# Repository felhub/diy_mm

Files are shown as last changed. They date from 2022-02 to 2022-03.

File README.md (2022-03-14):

# diy_mm

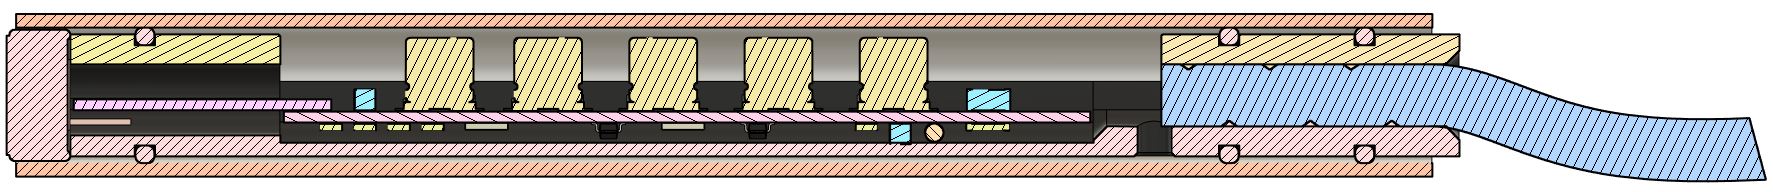
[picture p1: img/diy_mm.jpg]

Low cost (less than 10€) measurement microphone powered by +48V phantom power using a cheap electret capsule.
### Technical Data

| spec | value | unit | measured  |
|:---:|:---:|:---:|:---:|
| Frequency Response | 20 to 20000 &pm; 3dB  | Hz | n |
| Polar Pattern | Omnidirectional | - | n |
| Sensititvity | 0.013 | V/Pa @ 1kHz | y |
| Power requirements | +12 to +48 | V | y |
| Max acoustic input | 140dB | SPL | y |
| Output | XLR-3 (balanced) | - | - |
| Output Impedance | 100 | Ohm | y |
| Signal to Noise | 60dBA | SPL | n |
| Temp Operating Range  | -20 to 70 | °C | n |
| Dimensions L x D | 107.2 x 12 | mm | y |
| Weight | 16 (120 with 3m cable)| g | y |

### Measured Frequency Response

frequency response

## Impedance Converter and capsule adapter (kicad)

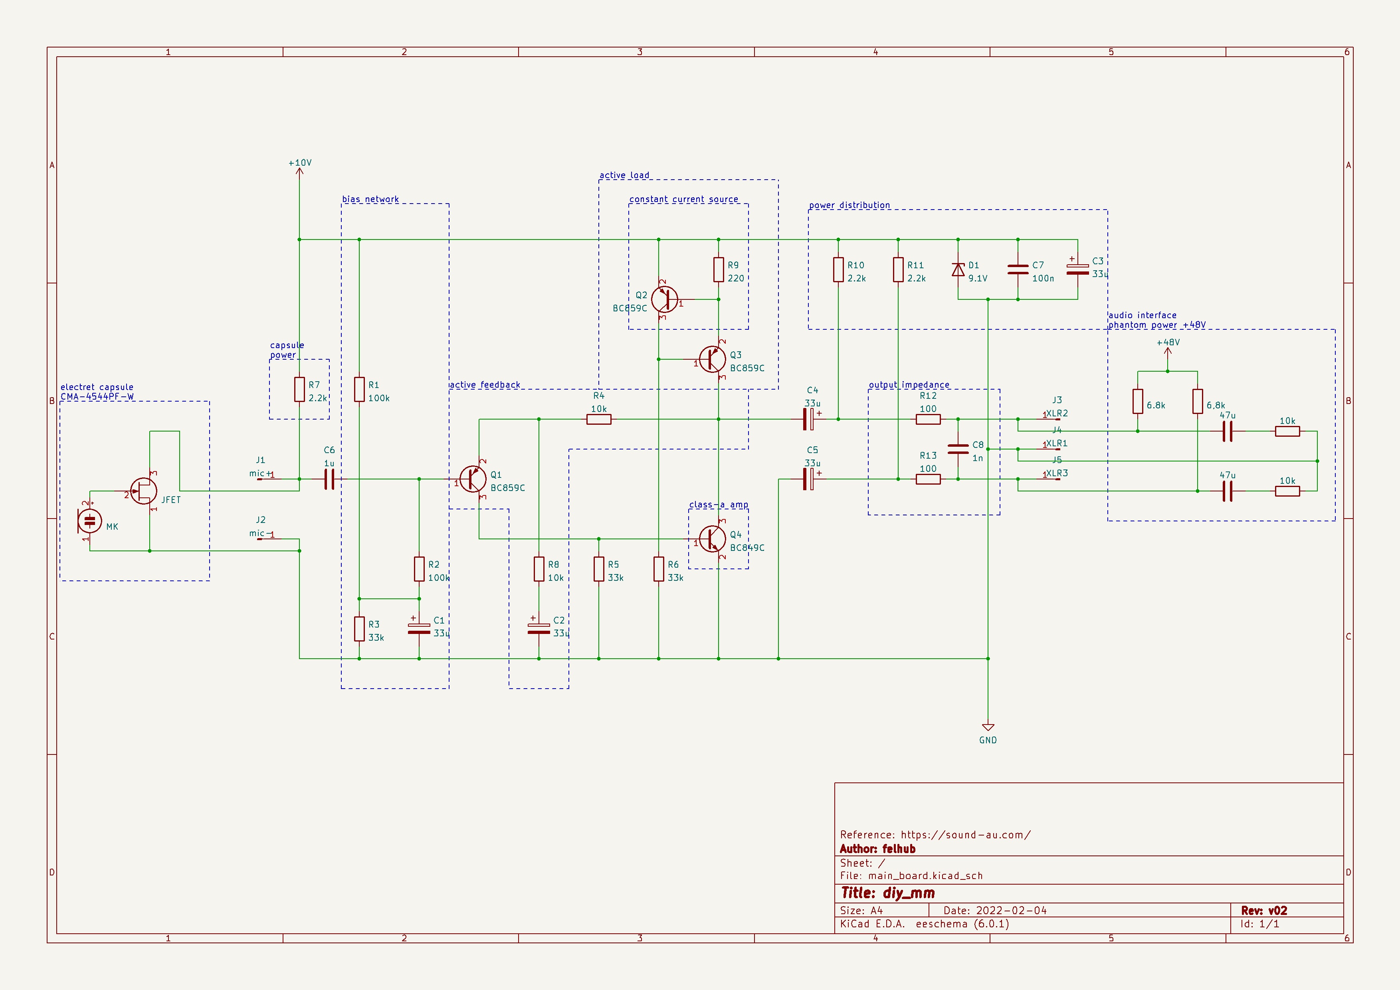
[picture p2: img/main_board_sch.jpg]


The impedance converter is based on an electret mic preamp from [Rod Elliot](https://sound-au.com), big thanks to the work he does on his site. He also has a store, where you can buy his original PCB for this amp, and many others. You can also donate there.  

Some changes were made to fit the converter to the capsule and to use smaller capacitors to fit it into the housing. Unfortunately these changes also effect the performance slightly.

In order to connect the PCB to the capsule and also to fix the capsule in place a small adapter PCB is used. This PCB is clamped in the 3d printed housing an soldered onto the converters PCB.

| main_board | capsule_adapter |
|:---:|:---:|
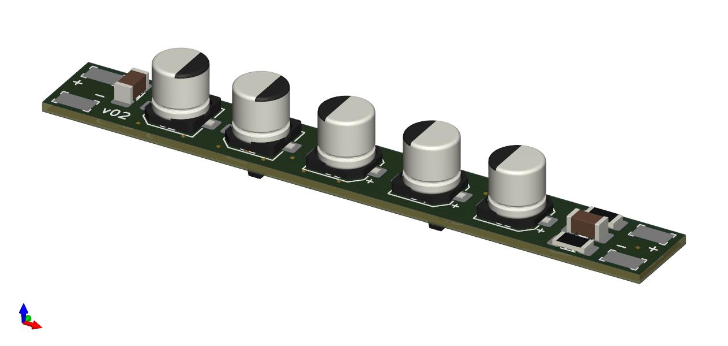
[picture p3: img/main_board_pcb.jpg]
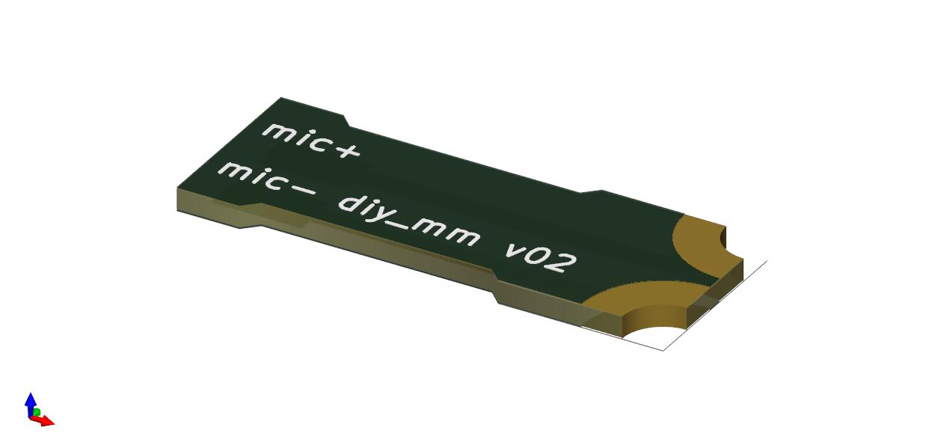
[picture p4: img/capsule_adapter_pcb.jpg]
|  |  |

## LTSpice Simulation (simulation)

Alongside the changes of the converter design a LTSpice simulation was conducted. The obtained result is very good, showing linearity of &pm;0.1dB and a very true phase slowly rising below 100Hz to reach \~13&deg; at 20Hz. The impedance converter also features a signal amplification of \~3dB.

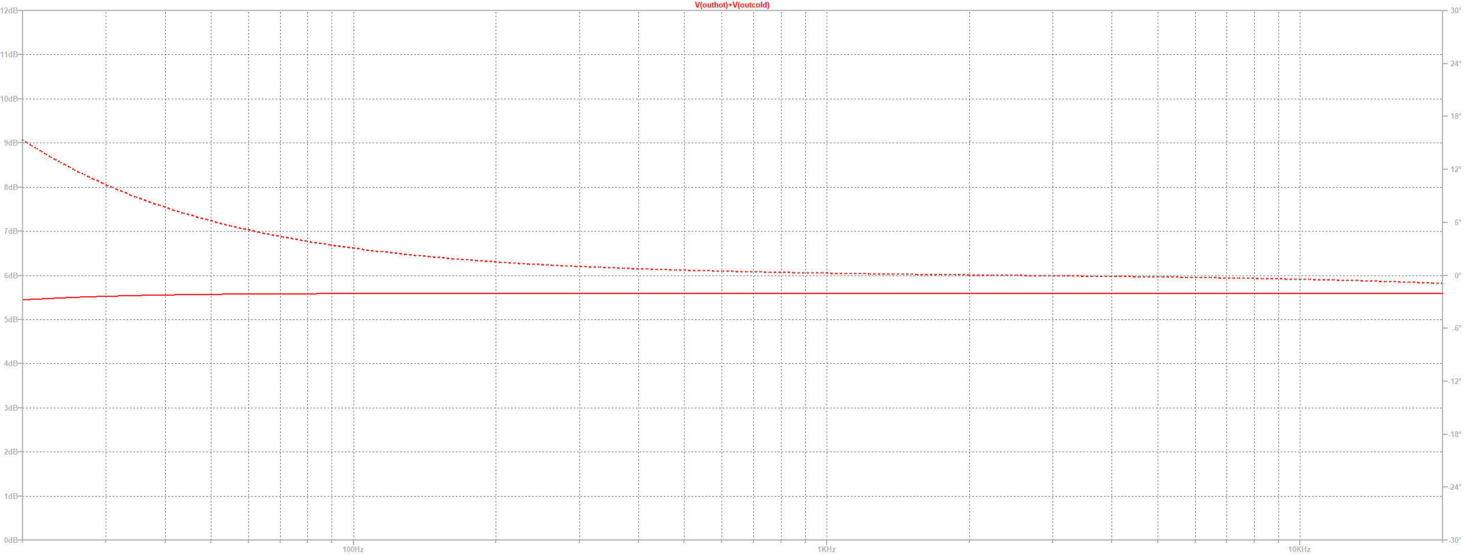
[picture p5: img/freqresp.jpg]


## 3D printed parts (3dfiles)

The fixture for capsule, impedance converter and strain relief if the cable are accomplished by three 3d printed parts. Using a 0.25mm nozzle the parts can be printed very accurately to perfectly fit the shielding aluminium tube using three o-rings.

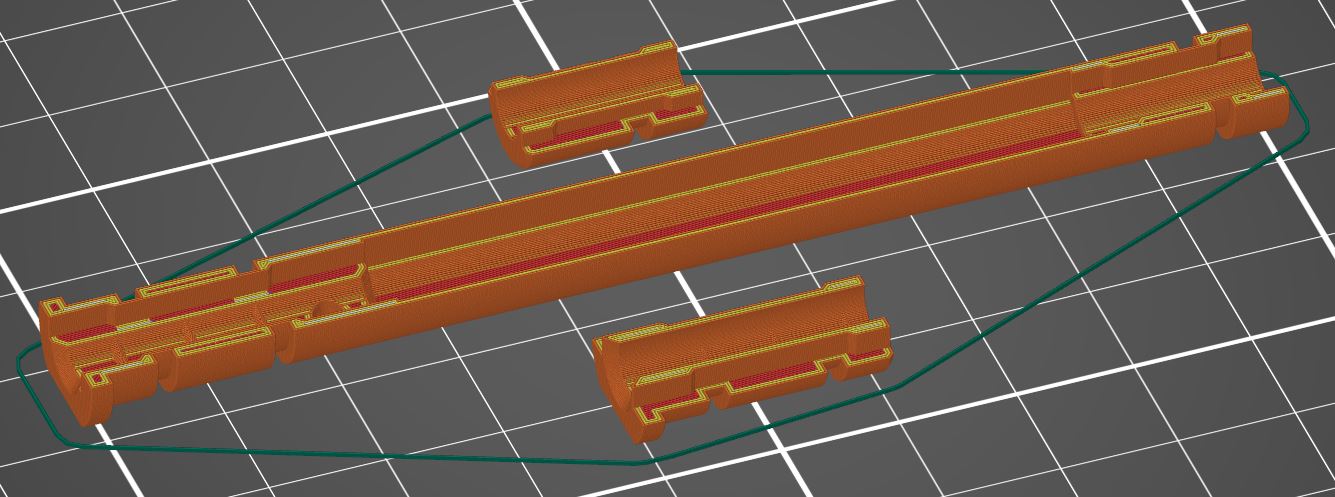
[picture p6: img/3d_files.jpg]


Through a hole in the chassis at the strain relief side, the shielding can be fed through in order to touch the aluminium tube. The hole assembly slides tightly inside and is just hold by friction. To get it back out one has to firstly pull on the cable slightly, after the first o-ring is out one should pull on the plastic to fully slide out the main assembly.

## Array configuration
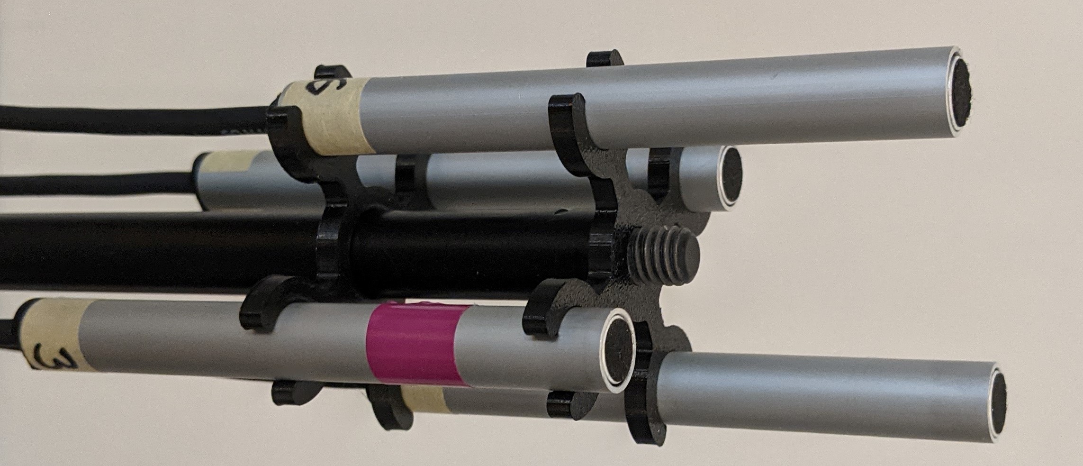
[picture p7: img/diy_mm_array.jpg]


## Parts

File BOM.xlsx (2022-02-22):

diy_mm
Bill of Materials
 |  |  |  |  |  |  |  |  | €9.369
Reference | Value | Footprint | Name | Comment | Supplier | Art. Nr. | Price/Pcs | Pcs | Total | Status
electric components
MK |  |  | CMA-4544PF-W | capsule | mouser.at | 490-CMA-4544PF-W | €0.620 | 1 | €0.62 | 30
Q1-Q3 |  | SOT-23-3 BEC | BC859C | pnp | conrad.at | 153145 | €0.080 | 3 | €0.24 | 90
Q4 |  | SOT-23-3 BEC | BC849C | npn | conrad.at | 152907 | €0.090 | 1 | €0.09 | 30
C1-C5 | 33u | 5x5.5 | WCAP-ASLI 865080442006 | 25v | mouser.at | 710-865080442006 | €0.164 | 5 | €0.82 | 150
C6 | 1u | 1206 | MLCC 885012208093 | ceramic | mouser.at | 710-885012208093 | €0.162 | 1 | €0.16 | 30
C7 | 100n | 1206 | MLCC 885012208087 | ceramic | mouser.at | 710-885012208087 | €0.090 | 1 | €0.09 | 30
C8 | 1n | 1206 | MLCC 885012208075 | ceramic | mouser.at | 710-885012208075 | €0.075 | 1 | €0.07 | 30
D1 | 10V | SOD-80C | Vishay 78-BZT55C9V1 | zener | mouser.at | 78-BZT55C9V1 | €0.165 | 1 | €0.17 | 30
R1-R2 | 100k | 1206 |  | 1% 0.25W | mouser.at | 652-CR1206FX-1003ELF | €0.013 | 2 | €0.03 | 60
R3, R5-R6 | 33k | 1206 |  | 1% 0.25W | mouser.at | 652-CR1206FX-3302ELF | €0.026 | 4 | €0.10 | 120
R4, R8 | 10k | 1206 |  | 1% 0.25W | mouser.at | 652-CR1206FX-1002ELF | €0.013 | 1 | €0.01 | 30
R9 | 220 | 1206 |  | 1% 0.25W | mouser.at | 652-CR1206FX-2200ELF | €0.032 | 1 | €0.03 | 30
R7, R10-R11 | 2.2k | 1206 |  | 1% 0.25W | mouser.at | 652-CR1206FX-2201ELF | €0.018 | 3 | €0.05 | 90
R12-R13 | 100 | 1206 |  | 1% 0.25W | mouser.at | 652-CR1206FX-1000ELF | €0.015 | 2 | €0.03 | 60
 |  |  | Sommer Cable The Goblin BK | per meter | thomann.de | 160823 | €1.090 | 3 | €3.27 | 90
 |  |  | Neutrik NC3 MXX | male XLR | thomann.de | 182696 | €2.880 | 1 | €2.88 | 30
mechanical components
 |  |  | Rundrohr Alu eloxiert 12x1 | per meter | hornbach.at | 6449190 | €3.040 | 0.104 | €0.32 | 3.12
 |  |  |  | incl. Shipping | jlcpcb.com |  | €0.174 | 1 | €0.17 | 30
 |  |  | NBR-70 O-Ring 6.00x1.50Ø | 3x | persicaner.at | 1571483 | €0.029 | 3 | €0.09 | 90
 |  |  | cable_clamp | 3d print |  |  | €0.030 | 1 | €0.03 | 30
 |  |  | capsule_clamp | 3d print |  |  | €0.020 | 1 | €0.02 | 30
 |  |  | chassis_oring | 3d print |  |  | €0.070 | 1 | €0.07 | 30

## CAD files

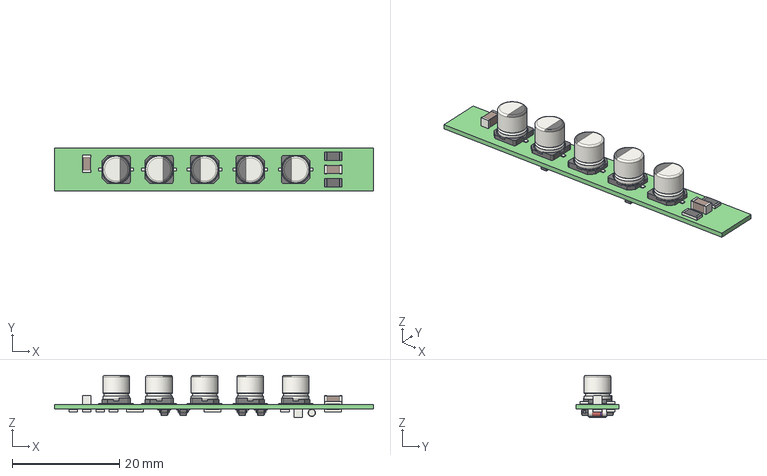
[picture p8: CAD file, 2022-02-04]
kicad/main_board/main_board.step
59.5 x 8.00 x 7.90 mm
main_board PCB

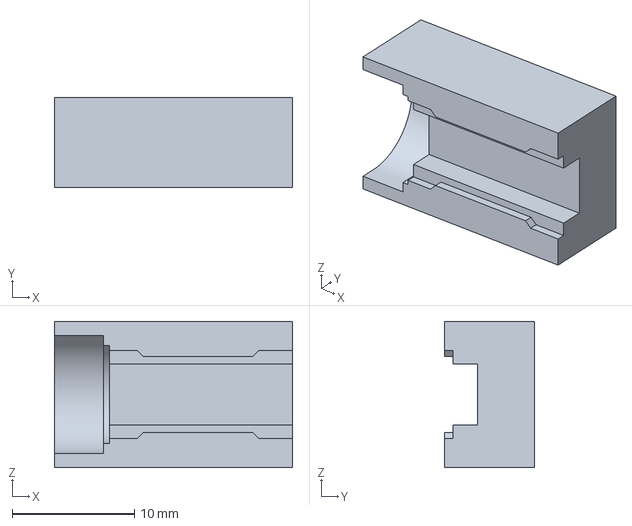
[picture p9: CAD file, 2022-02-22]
3d files/solder_jig.3mf
19.5 x 7.40 x 12.0 mm

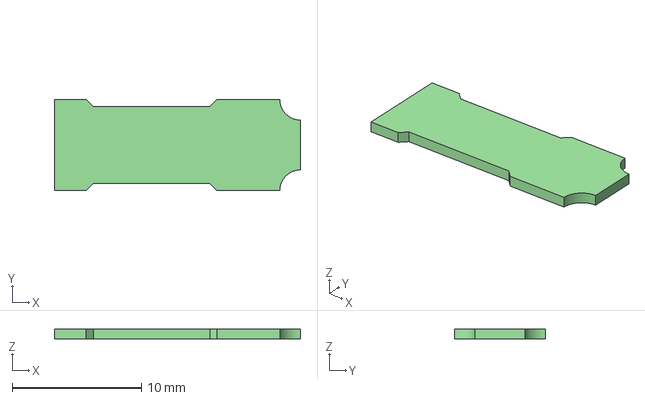
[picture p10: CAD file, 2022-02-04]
kicad/capsule_adapter/capsule_adapter.step
19.0 x 7.05 x 0.8 mm

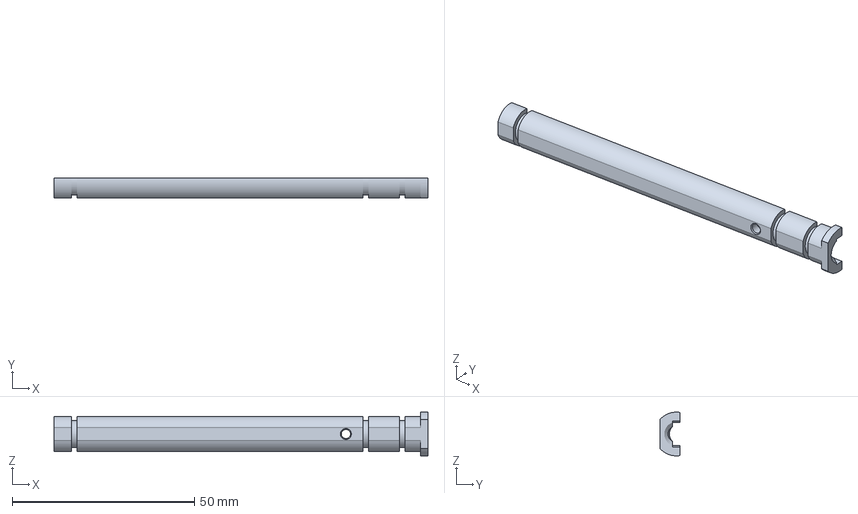
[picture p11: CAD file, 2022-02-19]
3d files/chassis.3mf
102.5 x 5.50 x 12.0 mm

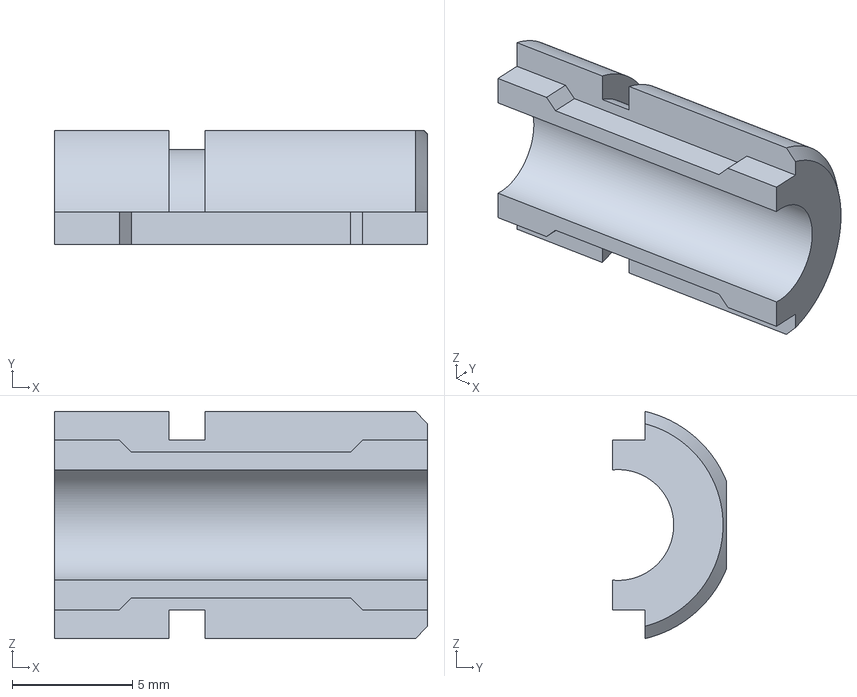
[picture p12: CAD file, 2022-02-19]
3d files/capsule_clamp.3mf
15.5 x 4.75 x 9.45 mm

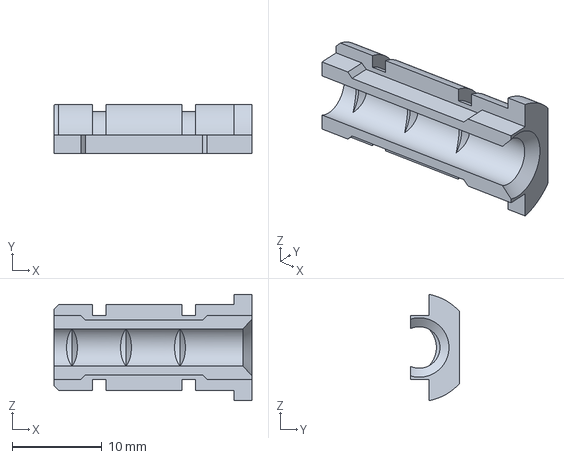
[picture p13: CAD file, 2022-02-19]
3d files/cable_clamp.3mf
22.0 x 5.50 x 11.8 mm

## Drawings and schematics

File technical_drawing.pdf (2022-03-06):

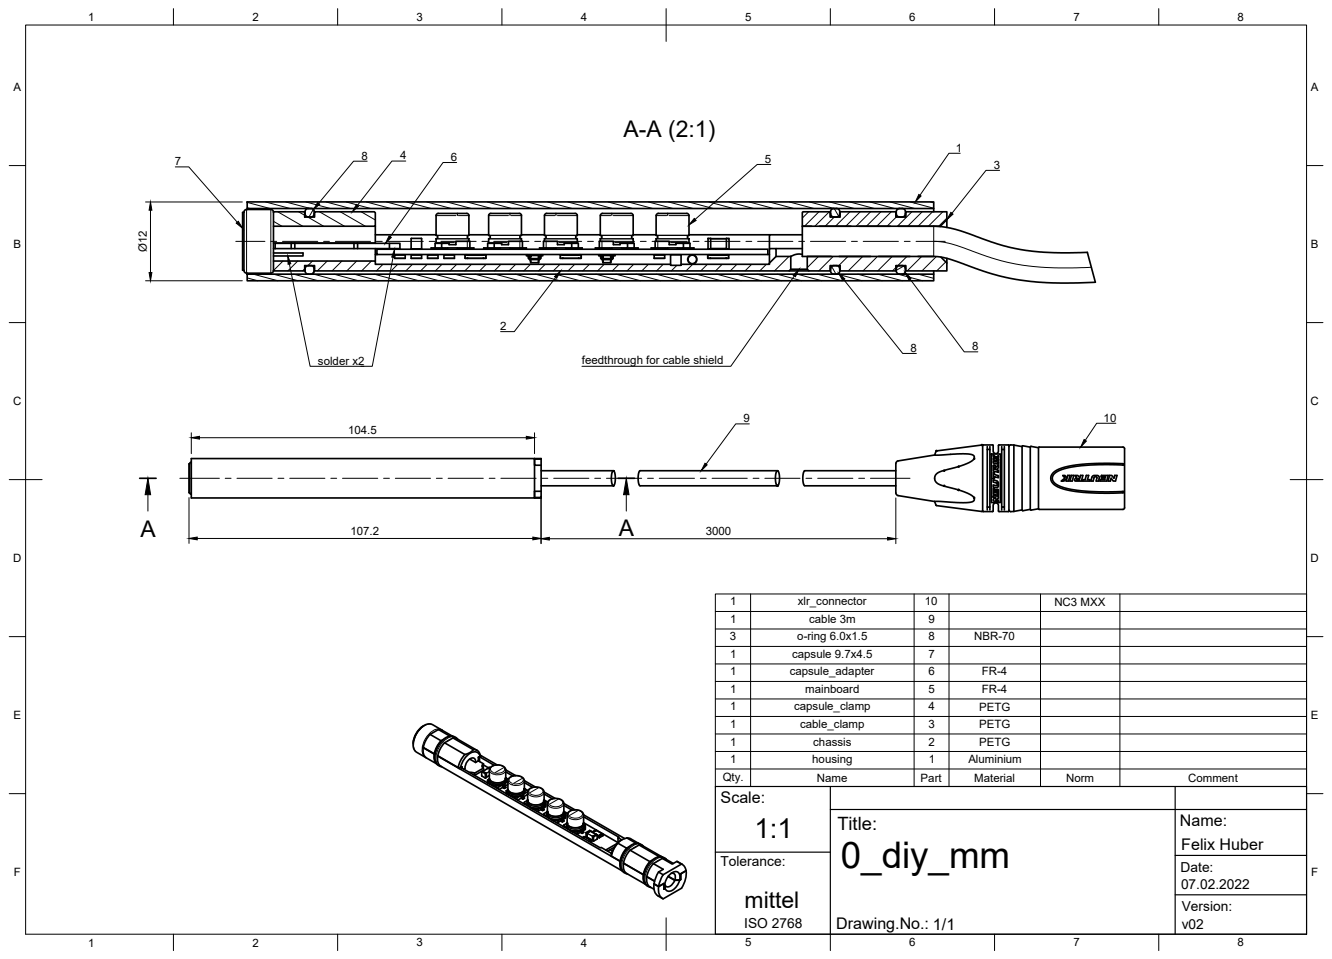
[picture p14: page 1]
ISO 2768; solder x2; feedthrough for cable shield

1 | xlr_connector | 10 | | NC3 MXX
1 | cable 3m | 9
3 | o-ring 6.0x1.5 | 8 | NBR-70
1 | capsule 9.7x4.5 | 7
1 | capsule_adapter | 6 | FR-4
1 | mainboard | 5 | FR-4
1 | capsule_clamp | 4 | PETG
1 | cable_clamp | 3 | PETG
1 | chassis | 2 | PETG
1 | housing | 1 | Aluminium
Qty. | Name | Part | Material | Norm | Comment
Scale: 1:1

Name: Felix Huber

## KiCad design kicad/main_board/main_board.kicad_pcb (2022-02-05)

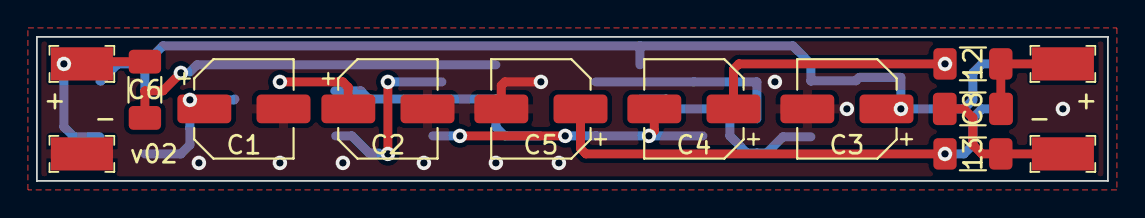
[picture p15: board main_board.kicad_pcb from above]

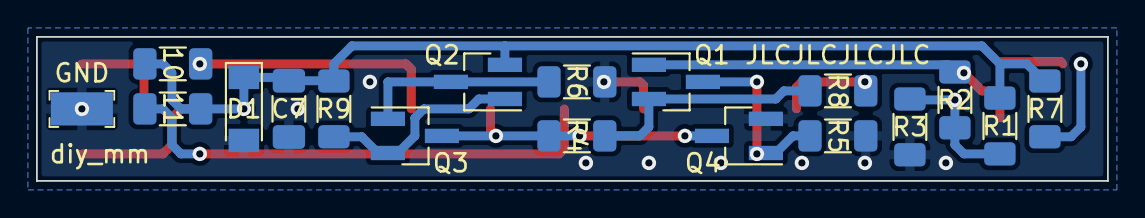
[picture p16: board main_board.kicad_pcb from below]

Board: 2 copper layers, 59.5 x 8.0 mm, 31 parts (18 on the bottom side), 15 nets.

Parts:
C1, C2, C3, C4, C5: 33u; CP_Elec_5x5.4
C6: 1u; C_1206_3216Metric_Pad1.33x1.80mm_HandSolder
C7: 100n; C_1206_3216Metric_Pad1.33x1.80mm_HandSolder
C8: 1n; C_1206_3216Metric_Pad1.33x1.80mm_HandSolder
D1: 9.1V; D_MiniMELF
J1: mic+; PC_TEST_POINT_SMD
J2: mic-; PC_TEST_POINT_SMD
J3: XLR2; PC_TEST_POINT_SMD
J4: XLR1; PC_TEST_POINT_SMD
J5: XLR3; PC_TEST_POINT_SMD
Q1, Q2, Q3: BC859C; SOT-23_Handsoldering
Q4: BC849C; SOT-23_Handsoldering
R1, R2: 100k; R_1206_3216Metric_Pad1.30x1.75mm_HandSolder
R3, R5, R6: 33k; R_1206_3216Metric_Pad1.30x1.75mm_HandSolder
R4, R8: 10k; R_1206_3216Metric_Pad1.30x1.75mm_HandSolder
R7, R10, R11: 2.2k; R_1206_3216Metric_Pad1.30x1.75mm_HandSolder
R9: 220; R_1206_3216Metric_Pad1.30x1.75mm_HandSolder
R12, R13: 100; R_1206_3216Metric_Pad1.30x1.75mm_HandSolder

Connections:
+10V: C3.1, C7.1, D1.1 (K), Q2.2 (E), R1.1, R7.1, R9.2, R10.2, R11.2
GND: C1.2, C2.2, C3.2, C5.2, C7.2, D1.2 (A), J2.1, J4.1, Q4.2 (E), R3.2, R5.2, R6.2
unnamed: C1.1, R1.2, R2.2, R3.1
unnamed: C2.1, R8.2
unnamed: C4.1, R10.1, R12.2
unnamed: C4.2, Q3.3 (C), Q4.3 (C), R4.2
unnamed: C5.1, R11.1, R13.2
unnamed: C6.1, J1.1, R7.2
unnamed: C6.2, Q1.1 (B), R2.1
unnamed: C8.1, J3.1, R12.1
unnamed: C8.2, J5.1, R13.1
unnamed: Q1.2 (E), R4.1, R8.1
unnamed: Q1.3 (C), Q4.1 (B), R5.1
unnamed: Q2.1 (B), Q3.2 (E), R9.1
unnamed: Q2.3 (C), Q3.1 (B), R6.1

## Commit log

2022-01-31 New try with readme file
    [DIY Mic Electronic.kicad_pcb, DIY Mic Electronic.sch]
2022-02-01 first full kicad push
    [BOM.xlsx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]
2022-02-03 redesign for KiCad 6.0.1
    [DIY Mic Electronic Panelized-B_Cu.gbl, DIY Mic Electronic Panelized-B_Mask.gbs, DIY Mic Electronic Panelized-B_Paste.gbp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]
2022-02-04 capsule adapter added
    [capsule_adapter.kicad_pcb, capsule_adapter.kicad_sch, capsule_adapter.step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]
2022-02-04 remove test
    [serial.xlsx]
2022-02-04 fixed silk at mounting holes
    [capsule_adapter.kicad_pcb]
2022-02-04 kicad headers updated, small simulation updates
    [main_board.kicad_pcb, main_board.kicad_sch]
2022-02-05 new R labeling, capsule pwr 2.2k
    [main_board.kicad_pcb, main_board.kicad_sch]
2022-02-05 small updates and new readme
    [BOM.xlsx, cable_clamp.3mf, capsule_adapter.kicad_pcb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]
2022-02-05 new BOM design
    [BOM.xlsx]
2022-02-05 pcb images view correction
2022-02-06 BOM updates
    [BOM.xlsx]
2022-02-13 new names and solder jig
    [chassis.3mf, chassis_oring.3mf, solder_jig.3mf]
2022-02-16 change print layout
    [BOM.xlsx]
2022-02-18 make electronics fully removeable
    [cable_clamp.3mf, chassis.3mf]
2022-02-19 minor model tweaks
    [cable_clamp.3mf, capsule_clamp.3mf, chassis.3mf]
2022-02-22 gain resistor R8 to 10k
    [BOM.xlsx, solder_jig.3mf]
2022-02-28 updated images
    [main_board.kicad_sch]
